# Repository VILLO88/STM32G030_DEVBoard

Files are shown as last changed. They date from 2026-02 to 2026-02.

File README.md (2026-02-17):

# STM32G030 Development Board

Demo

A compact STM32G030C8T6 development board designed for fast prototyping with breadboard-compatible pinout.

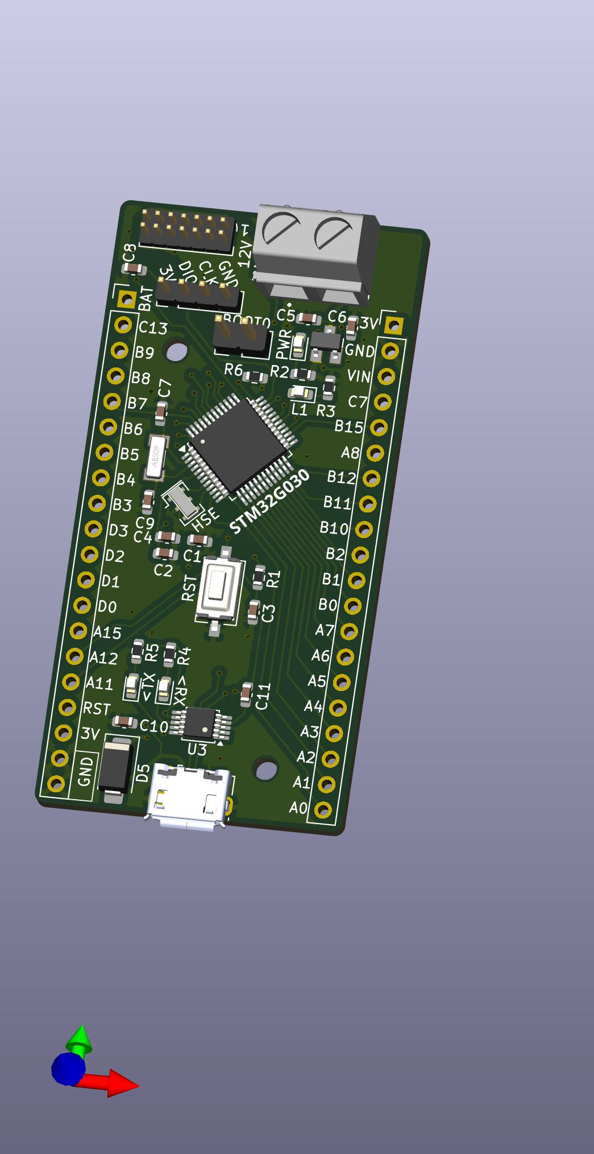
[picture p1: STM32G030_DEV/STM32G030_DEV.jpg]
Board Top View


## Features

- **MCU:** STM32G030C8T6 (ARM Cortex-M0+, 64KB Flash, 8KB RAM)
- **Voltage Regulator:** AP2210N-3.3V (low dropout, 300mA)
- **USB Interface:** Micro-USB with CH340E USB-to-Serial converter
- **Oscillators:**
  - 8MHz external resonator (HSE)
  - 32.768kHz crystal (LSE for RTC)
- **User LED:** Connected to PC6
- **Status LEDs:** Power, TX, RX
- **Buttons:** Reset, Wake-up
- **Boot Jumper:** For entering bootloader mode
- **Debug:** STDC14 connector compatible with ST-Link
- **Power Input:** USB or external via screw terminal (VIN)
- **GPIO:** 2x20 pin headers (2.54mm pitch) - breadboard friendly

## Pinout

### Side A (J4)
| Pin | Function |
|-----|---|
| A0-A7 | GPIO Port A |
| B0-B2 | GPIO Port B |
| B10-B12 | GPIO Port B |
| A8 | GPIO Port A |
| B15 | GPIO Port B |
| C7 | GPIO Port C |
| VIN | External Power Input |
| GND | Ground |
| 3V | 3.3V Output |

### Side B (J5)
| Pin | Function |
|-----|---|
| A11-A12 | GPIO Port A |
| A15 | GPIO Port A |
| D0-D3 | GPIO Port D |
| C1-C4 | GPIO Port C |
| B3-B9 | GPIO Port B |
| C13 | GPIO Port C |
| BAT | Battery Input |
| RST | Reset |
| 3V | 3.3V Output |
| GND | Ground |

## Programming

### Using ST-Link (SWD)
Connect to the STDC14 header or the 4-pin PROG header:
- Pin 1: VCC (3.3V)
- Pin 2: GND
- Pin 3: SWDIO
- Pin 4: SWCLK

### Using USB Bootloader
1. Close the BOOT jumper (JP1)
2. Press Reset or power cycle the board
3. Use STM32CubeProgrammer to flash via USB

### Using CH340E Serial
The onboard CH340E provides USB-to-Serial conversion for:
- Serial debugging/communication
- Programming via UART bootloader

## Power Supply

The board can be powered via:
- **USB:** 5V from Micro-USB connector
- **VIN:** External supply (5-12V) via screw terminal (J1)
- **3V:** Direct 3.3V supply (bypasses regulator)

Protection diode (SS14) prevents reverse polarity damage.

## Bill of Materials

| Component | Value | Package | Quantity |
|---|---|---|---|
| U2 | STM32G030C8Tx | LQFP-48 | 1 |
| U1 | AP2210N-3.3TRG1 | SOT-23-5 | 1 |
| U3 | CH340E | MSOP-10 | 1 |
| Y1 | 8MHz Resonator | SMD 3-pin | 1 |
| Y2 | 32.768kHz Crystal | ABS09 | 1 |
| D1 | Power LED | 0603 | 1 |
| D2 | User LED | 0603 | 1 |
| D3 | TX LED | 0603 | 1 |
| D4 | RX LED | 0603 | 1 |
| D5 | SS14 | SMA | 1 |
| J6 | USB Micro-B | Molex 105017 | 1 |

See `STM32G030_DEV/STM32G030_DEV.csv` for complete BOM.

## Board Images

### Top Side
Top View

### Bottom Side
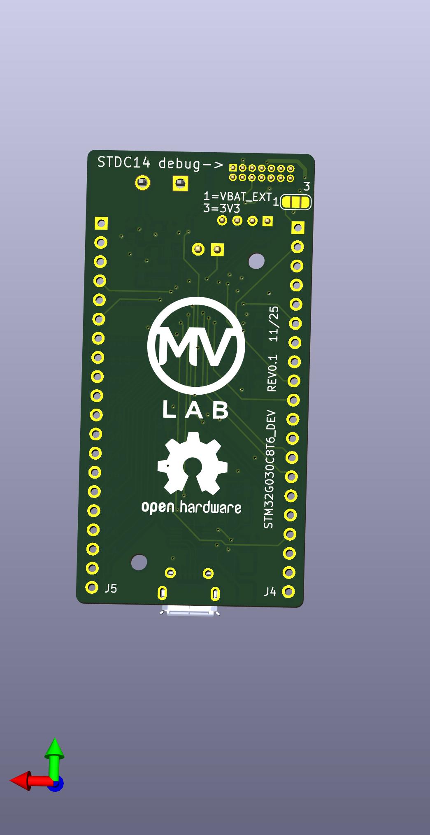
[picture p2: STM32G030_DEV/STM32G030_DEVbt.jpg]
Bottom View


## Design Files

- **Schematic & PCB:** KiCad 8 format in `STM32G030_DEV/`
- **Production Files:** Gerbers and assembly files in `STM32G030_DEV/production/`
- **Firmware:** STM32CubeIDE project in root directory

## Demo Firmware

The included STM32CubeIDE project is a test application that demonstrates UART communication by allowing the user to control the LED blink frequency via serial commands.

### Features
- User LED (PC6) blinks at a configurable frequency
- UART interface to change the blink frequency in real-time
- Uses the onboard CH340E USB-to-Serial converter

### Usage
1. Connect the board via USB
2. Open a serial terminal (115200 baud, 8N1)
3. Send commands to change the LED blink frequency

## Getting Started

1. Clone this repository
2. Open `PROGETTOCUBE.ioc` in STM32CubeMX to view/modify pin configuration
3. Open the project in STM32CubeIDE
4. Build and flash to the board

### Basic LED Control
The User LED is configured on PC6. Toggle it with:
```c
HAL_GPIO_TogglePin(USR_LED_GPIO_Port, USR_LED_Pin);
HAL_Delay(500);
```

## License

Open Hardware - See PCB silkscreen for details.

---
**Revision:** 0.1 (11/25)
**Design:** MV Lab

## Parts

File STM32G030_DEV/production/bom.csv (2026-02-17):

Designator | Footprint | Quantity | Value | LCSC Part #
C1, C10, C11, C3, C4, C8 | 0603 | 6 | 100n
C2 | 0603 | 1 | 10u
C5 | 0603 | 1 | 1u
C6 | 0603 | 1 | 2.2u
C7, C9 | 0603 | 2 | 22p
D1 | 0603 | 1 | POWER
D2 | 0603 | 1 | USER LED
D3 | 0603 | 1 | TX
D4 | 0603 | 1 | RX
D5 | D_SMA | 1 | SS14
J1 | CUI_TB002-500-02BE | 1 | Vin
J2 | PinHeader_1x04_P2.00mm_Vertical | 1 | PROG
J3 | PinHeader_2x07_P1.27mm_Vertical | 1 | Conn_mini3
J4 | PinHeader_1x20_P2.54mm_Vertical | 1 | A
J5 | PinHeader_1x20_P2.54mm_Vertical | 1 | B
J6 | USB_Micro-B_Molex-105017-0001 | 1 | USB_B_Micro
JP1 | PinHeader_1x02_P2.54mm_Vertical | 1 | BOOT
R1 | 0603 | 1 | 10k
R2, R3 | 0603 | 2 | 470
R4, R5 | 0603 | 2 | 1K
SW1 | SW_Tactile_SPST_NO_Straight_CK_PTS636Sx25SMTRLFS | 1 | wake-up
U1 | AP2210N-3.3TRG1 | 1 | AP2210N-3.3TRG1 | AP2210N-3.3TRG1
U2 | LQFP-48_7x7mm_P0.5mm | 1 | STM32G030C8Tx
U3 | MSOP10 | 1 | CH340E
Y1 | Resonator_SMD_Murata_CSTxExxV-3Pin_3.0x1.1mm | 1 | 8mhz
Y2 | XTAL_ABS09-32.768KHZ-T | 1 | Crystal

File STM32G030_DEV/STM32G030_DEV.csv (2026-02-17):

Id | Designator | Footprint | Quantity | Designation | Supplier and ref
1 | Y1 | Resonator_SMD_Murata_CSTxExxV-3Pin_3.0x1.1mm | 1 | 8mhz
2 | C11,C3,C8,C10,C4,C1 | C_0603_1608Metric | 6 | 100n
3 | C2 | C_0603_1608Metric | 1 | 10u
4 | D3 | LED_0603_1608Metric | 1 | TX
5 | R5,R4 | R_0603_1608Metric | 2 | 1K
6 | JP1 | PinHeader_1x02_P2.54mm_Vertical | 1 | BOOT
7 | Y2 | XTAL_ABS09-32.768KHZ-T | 1 | Crystal
8 | J5 | PinHeader_1x20_P2.54mm_Vertical | 1 | B
9 | U1 | AP2210N-3.3TRG1 | 1 | AP2210N-3.3TRG1
10 | J2 | PinHeader_1x04_P2.00mm_Vertical | 1 | PROG
11 | D5 | D_SMA | 1 | SS14
12 | SW1 | SW_Tactile_SPST_NO_Straight_CK_PTS636Sx25SMTRLFS | 1 | wake-up
13 | J3 | PinHeader_2x07_P1.27mm_Vertical | 1 | Conn_mini3
14 | R2,R3 | R_0603_1608Metric | 2 | 470
15 | J1 | CUI_TB002-500-02BE | 1 | Vin
16 | C7,C9 | C_0603_1608Metric | 2 | 22p
17 | U3 | MSOP10 | 1 | CH340E
18 | D2 | LED_0603_1608Metric | 1 | USER LED
19 | J6 | USB_Micro-B_Molex-105017-0001 | 1 | USB_B_Micro
20 | U2 | LQFP-48_7x7mm_P0.5mm | 1 | STM32G030C8Tx
21 | C6 | C_0603_1608Metric | 1 | 2.2u
22 | J4 | PinHeader_1x20_P2.54mm_Vertical | 1 | A
23 | D4 | LED_0603_1608Metric | 1 | RX
24 | R1 | R_0603_1608Metric | 1 | 10k
25 | D1 | LED_0603_1608Metric | 1 | POWER
26 | C5 | C_0603_1608Metric | 1 | 1u

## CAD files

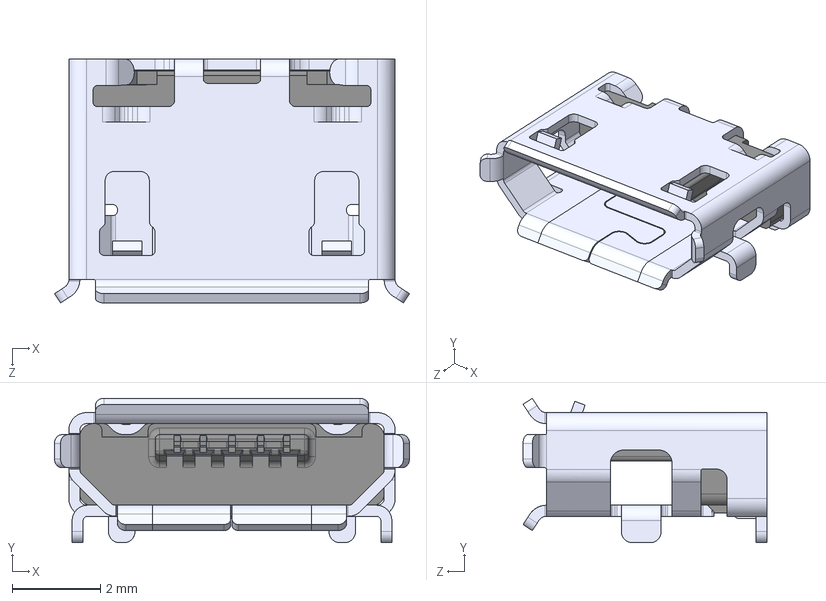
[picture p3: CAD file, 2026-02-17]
STM32G030_DEV/3D/10118194_0001LF (1)/microusb.step
8.05 x 3.27 x 5.53 mm

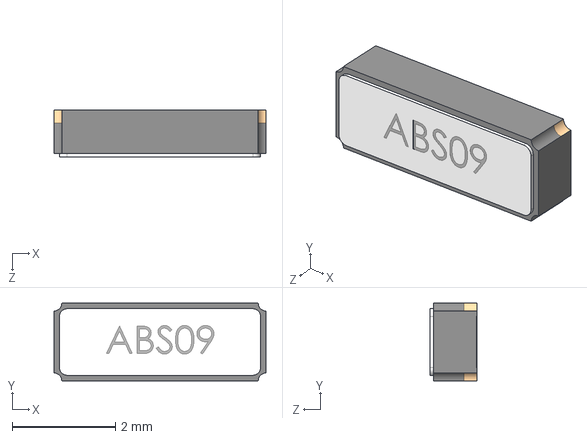
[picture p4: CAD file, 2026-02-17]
STM32G030_DEV/3D/ABS09_32_768KHZ_T/ABS09-32.768KHZ-T.step
4.10 x 1.50 x 0.9 mm

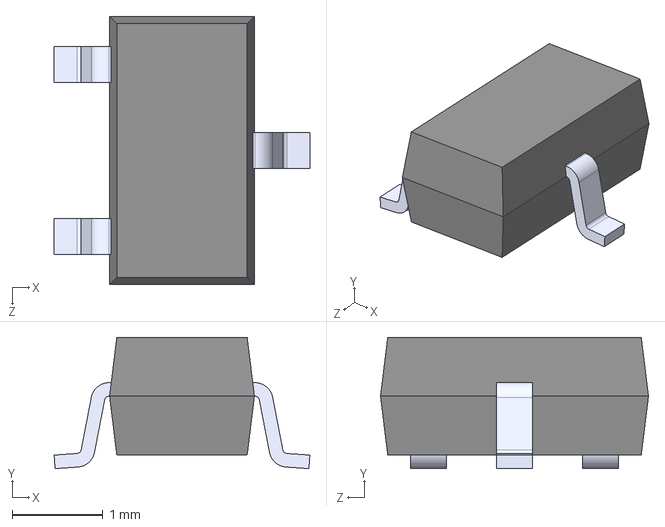
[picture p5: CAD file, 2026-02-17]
STM32G030_DEV/3D/AP2210N_3_3TRG1/AP2210N-3.3TRG1.step
2.83 x 1.45 x 2.96 mm

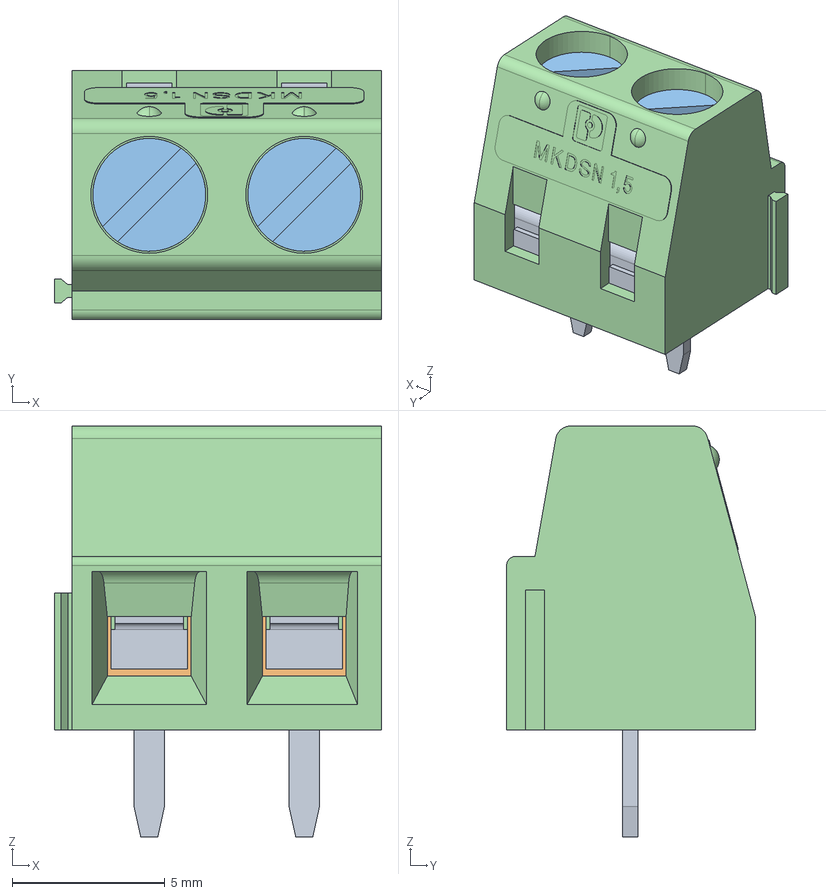
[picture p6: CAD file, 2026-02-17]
STM32G030_DEV/3D/1729128/1729128.stp
10.7 x 8.15 x 13.5 mm

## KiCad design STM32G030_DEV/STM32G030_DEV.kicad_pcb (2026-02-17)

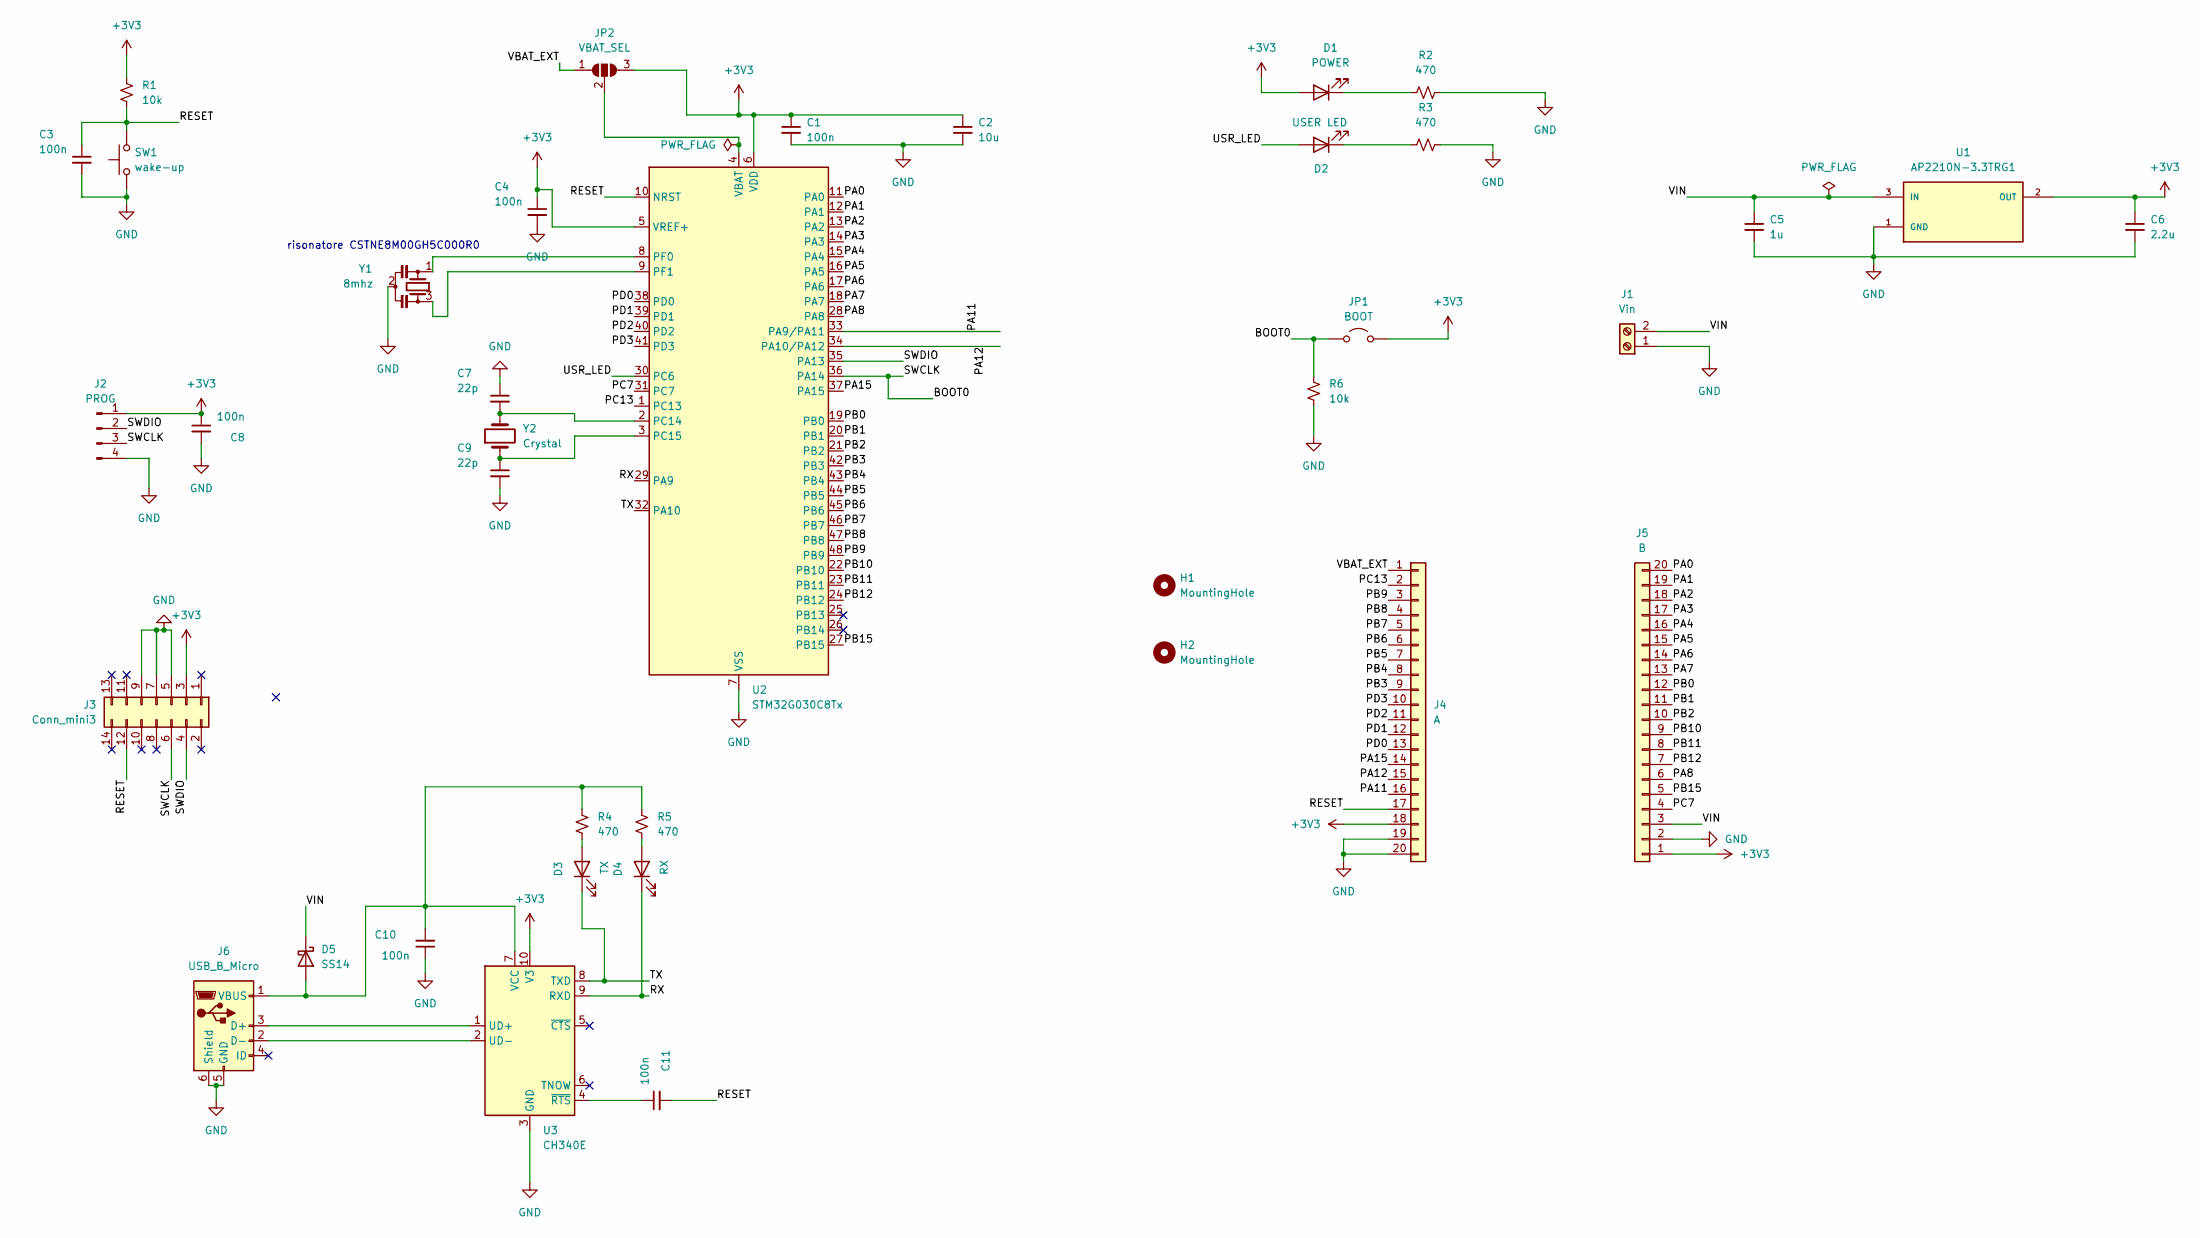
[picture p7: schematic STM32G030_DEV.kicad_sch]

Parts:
C1, C3, C4, C8, C10, C11: 100n; C_0603_1608Metric
C2: 10u; C_0603_1608Metric
C5: 1u; C_0603_1608Metric
C6: 2.2u; C_0603_1608Metric
C7, C9: 22p; C_0603_1608Metric
D1: POWER; LED_0603_1608Metric
D2: USER LED; LED_0603_1608Metric
D3: TX; LED_0603_1608Metric
D4: RX; LED_0603_1608Metric
D5: SS14; D_SMA
H1, H2: MountingHole; MountingHole_2.2mm_M2_ISO14580
J1: Vin; CUI_TB002-500-02BE
J2: PROG; PinHeader_1x04_P2.00mm_Vertical
J3: Conn_mini3; PinHeader_2x07_P1.27mm_Vertical
J4: A; PinHeader_1x20_P2.54mm_Vertical
J5: B; PinHeader_1x20_P2.54mm_Vertical
J6: USB_B_Micro; USB_Micro-B_Molex-105017-0001
JP1: BOOT; PinHeader_1x02_P2.54mm_Vertical
JP2: VBAT_SEL; SolderJumper-3_P1.3mm_Open_RoundedPad1.0x1.5mm_NumberLabels
R1, R6: 10k; R_0603_1608Metric
R2, R3, R4, R5: 470; R_0603_1608Metric
SW1: wake-up; SW_Tactile_SPST_NO_Straight_CK_PTS636Sx25SMTRLFS
U1: AP2210N-3.3TRG1; MPN AP2210N-3.3TRG1
U2: STM32G030C8Tx; LQFP-48_7x7mm_P0.5mm
U3: CH340E; MSOP-10_3x3mm_P0.5mm
Y1: 8mhz; Resonator_SMD_Murata_CSTxExxV-3Pin_3.0x1.1mm
Y2: Crystal; XTAL_ABS09-32.768KHZ-T

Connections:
+3V3: C1.1, C2.1, C4.1, C6.1, C8.1, D1.2 (A), J2.1, J3.3, J4.18, J5.1, JP1.2 (B), JP2.3 (B), R1.1, U1.2 (OUT), U2.5 (VREF+), U2.6 (VDD), U3.10 (V3)
/BOOT0: J2.3, J3.6, JP1.1 (A), R6.2, U2.36 (PA14)
/PA0: J5.20, U2.11 (PA0)
/PA1: J5.19, U2.12 (PA1)
/PA2: J5.18, U2.13 (PA2)
/PA3: J5.17, U2.14 (PA3)
/PA4: J5.16, U2.15 (PA4)
/PA5: J5.15, U2.16 (PA5)
/PA6: J5.14, U2.17 (PA6)
/PA7: J5.13, U2.18 (PA7)
/PA8: J5.6, U2.28 (PA8)
/PA11: J4.16, U2.33 (PA9/PA11)
/PA12: J4.15, U2.34 (PA10/PA12)
/PA15: J4.14, U2.37 (PA15)
/PB0: J5.12, U2.19 (PB0)
/PB1: J5.11, U2.20 (PB1)
/PB2: J5.10, U2.21 (PB2)
/PB3: J4.9, U2.42 (PB3)
/PB4: J4.8, U2.43 (PB4)
/PB5: J4.7, U2.44 (PB5)
/PB6: J4.6, U2.45 (PB6)
/PB7: J4.5, U2.46 (PB7)
/PB8: J4.4, U2.47 (PB8)
/PB9: J4.3, U2.48 (PB9)
/PB10: J5.9, U2.22 (PB10)
/PB11: J5.8, U2.23 (PB11)
/PB12: J5.7, U2.24 (PB12)
/PB15: J5.5, U2.27 (PB15)
/PC7: J5.4, U2.31 (PC7)
/PC13: J4.2, U2.1 (PC13)
/PD0: J4.13, U2.38 (PD0)
/PD1: J4.12, U2.39 (PD1)
/PD2: J4.11, U2.40 (PD2)
/PD3: J4.10, U2.41 (PD3)
/RESET: C3.1, C11.2, J3.12, J4.17, R1.2, SW1.2, U2.10 (NRST)
/RX: D4.1 (K), U2.29 (PA9), U3.9 (RXD)
/SWDIO: J2.2, J3.4, U2.35 (PA13)
/TX: D3.1 (K), U2.32 (PA10), U3.8 (TXD)
/USR_LED: D2.2 (A), U2.30 (PC6)
/VBAT_EXT: J4.1, JP2.1 (A)
/VIN: C5.1, D5.1 (K), J1.2, J5.3, U1.3 (IN)
GND: C1.2, C2.2, C3.2, C4.2, C5.2, C6.2, C7.1, C8.2, C9.2, C10.1, J1.1, J2.4, J3.5, J3.7, J3.9, J4.19, J4.20, J5.2, J6.5 (GND), J6.6 (Shield), R2.2, R3.2, R6.1, SW1.1, U1.1 (GND), U2.7 (VSS), U3.3 (GND), Y1.2
unnamed: D1.1 (K), R2.1
unnamed: D2.1 (K), R3.1
unnamed: D3.2 (A), R4.2
unnamed: D4.2 (A), R5.2
unnamed: C10.2, D5.2 (A), J6.1 (VBUS), R4.1, R5.1, U3.7 (VCC)
unnamed: J6.3 (D+), U3.1 (UD+)
unnamed: J6.2 (D-), U3.2 (UD-)
unnamed: JP2.2 (C), U2.4 (VBAT)
unnamed: C7.2, U2.2 (PC14), Y2.2
unnamed: C9.1, U2.3 (PC15), Y2.1
unnamed: U2.8 (PF0), Y1.1
unnamed: U2.9 (PF1), Y1.3
unnamed: C11.1, U3.4 (~RTS)

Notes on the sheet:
risonatore CSTNE8M00GH5C000R0

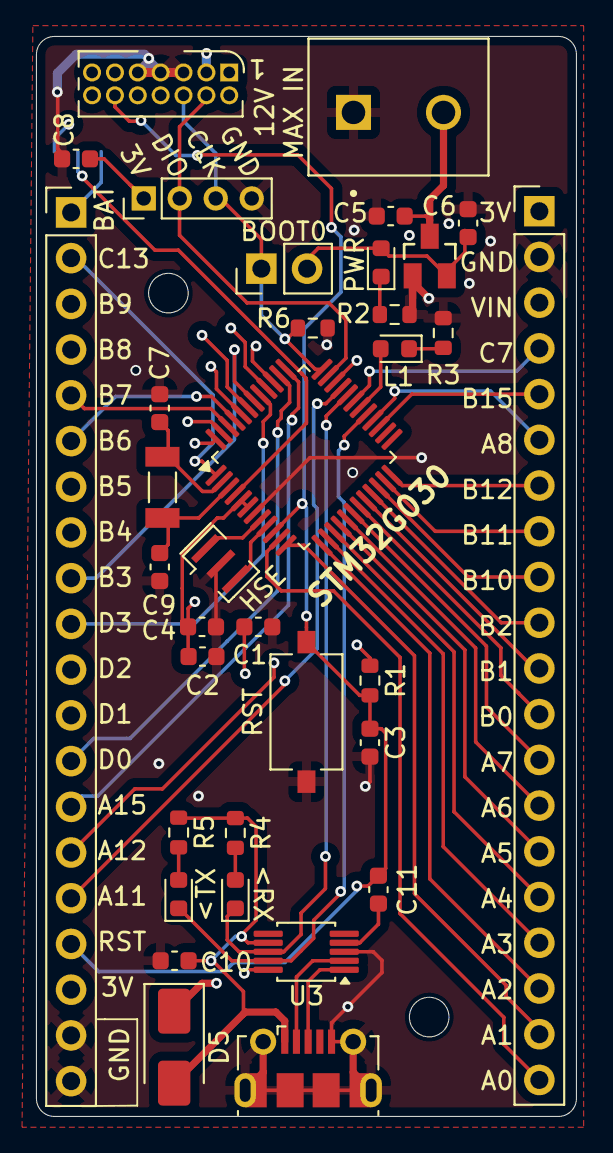
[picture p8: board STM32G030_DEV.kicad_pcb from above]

Board: 4 copper layers, 30.0 x 60.0 mm, 38 parts (1 on the bottom side), 55 nets.

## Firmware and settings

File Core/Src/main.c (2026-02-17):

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
/* Includes ------------------------------------------------------------------*/
#include "main.h"

UART_HandleTypeDef huart1;

/* USER CODE BEGIN PV */
char tx_data[]= "Seleziona la frequenza di lampeggio: 1,2 o 3 \r\n";
char rx_data[2];  /* +1 byte per il null terminator */
volatile uint32_t blink_period_ms = 0;   /* 0 = led spento */
uint32_t last_toggle_tick = 0;
/* USER CODE END PV */

void SystemClock_Config(void);
static void MX_GPIO_Init(void);
static void MX_USART1_UART_Init(void);
/**
  * @brief  The application entry point.
  * @retval int
  */
int main(void)
{

  /* MCU Configuration--------------------------------------------------------*/

  /* Reset of all peripherals, Initializes the Flash interface and the Systick. */
  HAL_Init();

  /* Configure the system clock */
  SystemClock_Config();

  /* Initialize all configured peripherals */
  MX_GPIO_Init();
  MX_USART1_UART_Init();
  /* USER CODE BEGIN 2 */
  HAL_UART_Transmit(&huart1, (uint8_t*)tx_data, sizeof(tx_data)-1, HAL_MAX_DELAY);
  HAL_UART_Receive_IT(&huart1, (uint8_t*)rx_data, 1);
  /* USER CODE END 2 */

  /* Infinite loop */
  /* USER CODE BEGIN WHILE */
  while (1)
  {
    /* USER CODE END WHILE */

    /* USER CODE BEGIN 3 */
	if (blink_period_ms > 0)
	{
	    uint32_t now = HAL_GetTick();
	    if ((now - last_toggle_tick) >= blink_period_ms)
	    {
	        HAL_GPIO_TogglePin(USR_LED_GPIO_Port, USR_LED_Pin);
	        last_toggle_tick = now;
	    }
	}
	else
	{
	    HAL_GPIO_WritePin(USR_LED_GPIO_Port, USR_LED_Pin, GPIO_PIN_RESET);
	}
  }
  /* USER CODE END 3 */
}

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
/* USER CODE BEGIN 4 */
void HAL_UART_RxCpltCallback(UART_HandleTypeDef *huart)
{
  /* Prevent unused argument(s) compilation warning */
  UNUSED(huart);

  /* NOTE : This function should not be modified, when the callback is needed,
            the HAL_UART_RxCpltCallback can be implemented in the user file.
   */
  /* Echo del carattere ricevuto */
    HAL_UART_Transmit(&huart1, (uint8_t*)rx_data, 1, HAL_MAX_DELAY);

    if (rx_data[0] == '1') {
        blink_period_ms = 500;   /* toggle ogni 500ms → periodo completo 1s */
    }
    else if (rx_data[0] == '2') {
        blink_period_ms = 200;   /* toggle ogni 200ms → periodo completo 400ms */
    }
    else if (rx_data[0] == '3') {
        blink_period_ms = 25;    /* toggle ogni 25ms  → periodo completo 50ms */
    }

    /* Riarma la ricezione per il prossimo byte */
    HAL_UART_Receive_IT(&huart1, (uint8_t*)rx_data, 1);
}
/* USER CODE END 4 */
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


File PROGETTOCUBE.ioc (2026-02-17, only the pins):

Mcu.UserName=STM32G030C8Tx
PA10.Signal=USART1_RX
PA13.Signal=SYS_SWDIO
PA14-BOOT0.Signal=SYS_SWCLK
PA9.Signal=USART1_TX
PC6.GPIO_Label=USR_LED
PC6.Signal=GPIO_Output

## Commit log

2026-02-17 Add KiCad PCB design files
    [1729128.stp, ABS09-32.768KHZ-T.step, AP2210N-3.3TRG1.step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]
2026-02-17 Add detailed README with board documentation

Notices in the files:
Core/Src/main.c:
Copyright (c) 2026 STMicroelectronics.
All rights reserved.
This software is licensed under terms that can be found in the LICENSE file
